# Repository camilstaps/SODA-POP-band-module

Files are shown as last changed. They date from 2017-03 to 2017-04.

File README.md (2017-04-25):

# SODA POP band module
This repository contains Eagle files for band modules for the
[SODA POP][sodapop] by [Steve Weber KD1JV][kd1jv]. The SODA POP was originally
designed as a single band QRP CW transceiver on a 3.6" square board. The mods
described below make it a multi-bander.

**Warning**: I have not actually tried to use these files yet. They may have
errors. I shall in no event be liable for any claim, damages or other
liability, whether in action of contract, tort or otherwise, arising from, out
of or in connection with these files or their use.

Two versions are available: one with headers and either through-hole or SMT
components; one with SMT components and a DB9 connector. The DB9 one has an
option for automatic band selection. Some modifications have to be made to the
main board for both modules.

The most recent version of these modules can be ordered from OSH Park from
https://oshpark.com/profiles/PD7LOL.

---

- [Common mods](#common-mods)
- [Through-hole / SMT module with headers](#through-hole--smt-module-with-headers)
- [SMT module with DB9 connector](#smt-module-with-db9-connector)
- [SMT module with DB9 connector and auto band selection](#smt-module-with-db9-connector-and-auto-band-selection)
- [Horizontal format SMT module with DB9 connector and auto band selection](#horizontal-format-smt-module-with-db9-connector-and-auto-band-selection)
- [Author &amp; license](#author--license)

---

## Common mods

### Main board
- The following components are moved to the band module:
	- **TX**: C2, C3, C5 (and C6), C12, L7, L8
	- **RX**: L3, CT1, C31, CT2, L4

	Their values can be taken from the manual under "Band specific parts". One
	part, C31, is on the band module even though it has a fixed value (5p).

### Software
- The software has to be adapted as described in the manual under "Manual band
  selection".

## Through-hole / SMT module With headers
- L3 has to be shorted (on the main board).
- Add 2-pin female headers on the place of L7 and L8
- Add 3-pin female headers on the place of CT1 and CT2 (middle pin should be
  removed)

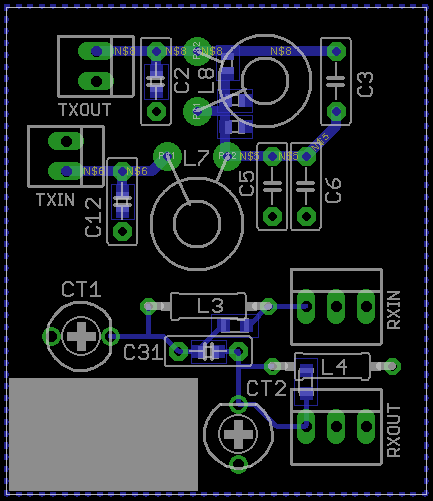
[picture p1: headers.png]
The PCB layout for <160m


If you want to make a 160m module with through-hole components, the layout is
slightly different to make room for the T50-2 toroids. Also, C31 is removed in
this case, and L4 is omitted (as in the manual). If building with SMT
components, you can use the same layout as for the other modules, short C31 and
leave out L4.

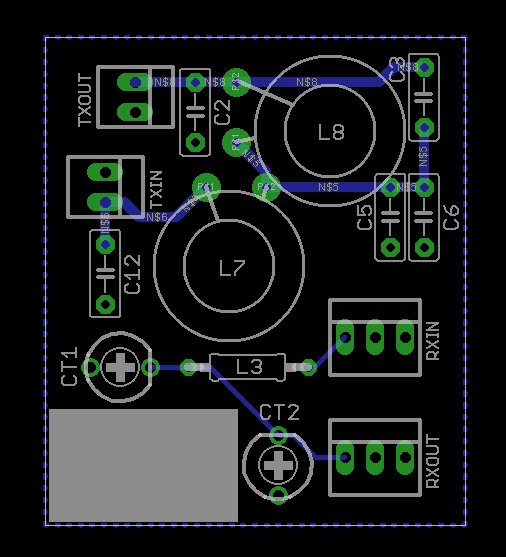
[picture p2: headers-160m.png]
The PCB layout for 160m


For 80m, there is no separate layout. Simply leave L4 empty and short C31.

For 60m and 80m, the T37-2 should fit on the normal board.

When plugged in, these band modules cover the ON/OFF switch on the main board.
I would suggest either mounting the switch on the case or omitting it (and turn
the rig on and off by applying and disconnecting a battery or power jack).

## SMT module with DB9 connector
- Add a (male) connector to the main board using short coax cables. The parts
  you should connect are L3, CT2, L7 and L8.

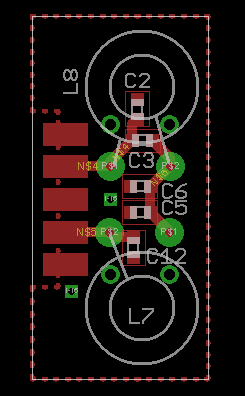
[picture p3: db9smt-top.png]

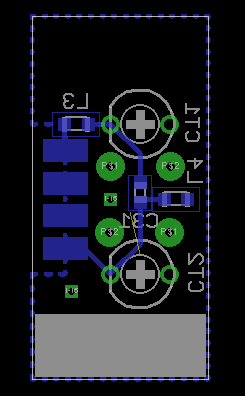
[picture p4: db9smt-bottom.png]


These files show T37-2 toroids, so they should work for all bands except 160m.
The T50-2 toroids for 160m will not fit any more, so they will extend beyond
the board boundaries.

The PCB is placed between the two rows of the DB9 connector.

## SMT module with DB9 connector and auto band selection
This is a very nice mod to the above module, contributed by
[David, VK3IL][vk3il]. It adds a [PCA9536][pca9536] that can be connected to
the I2C pins of the SODA POP controller to add automatic band selection. For
this, the firmware needs to be updated.

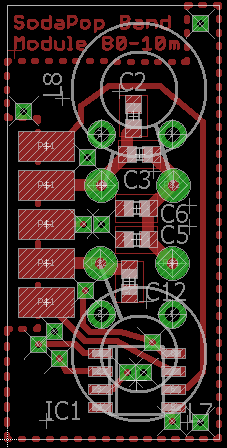
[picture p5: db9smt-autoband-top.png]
PCB layout for SMT/DB9/autoband, <160m

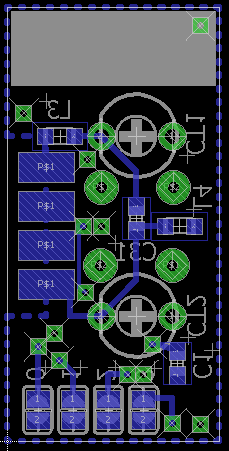
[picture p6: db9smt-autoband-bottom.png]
PCB layout for SMT/DB9/autoband, <160m


## Horizontal format SMT module with DB9 connector and auto band selection
This version is designed to mount parallel and above the main board using a
female DB9 connector on the module. It includes the auto-band selection feature
and is sized to support T30 to T50 size toroids so can be used for 160-10m
bands.

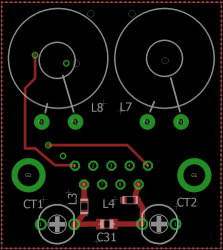
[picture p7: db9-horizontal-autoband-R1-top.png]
PCB layout for Horizontal SMT/DB9/autoband

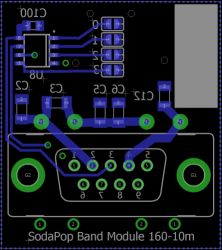
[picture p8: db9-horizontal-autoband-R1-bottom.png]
PCB layout for Horizontal SMT/DB9/autoband


## Author &amp; License
These files were made by [Camil Staps][cs], PD7LOL and [David Giddy][vk3il],
VK3IL. They are hereby placed in the public domain.

[cs]: https://camilstaps.nl
[kd1jv]: http://kd1jv.qrpradio.com/
[pca9536]: http://www.nxp.com/documents/data_sheet/PCA9536.pdf
[sodapop]: https://groups.yahoo.com/neo/groups/AT_Sprint/files/SODA%20POP/
[vk3il]: http://www.vk3il.net/

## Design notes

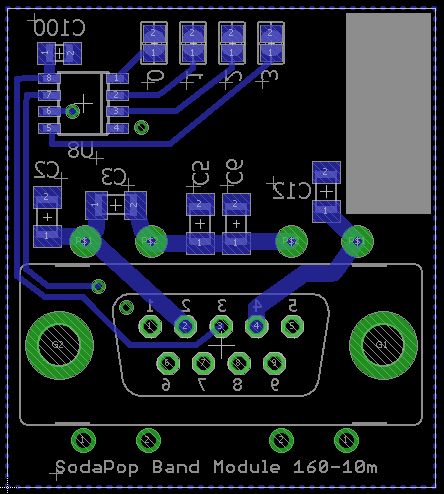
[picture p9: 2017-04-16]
db9-horizontal-autoband-bottom.png

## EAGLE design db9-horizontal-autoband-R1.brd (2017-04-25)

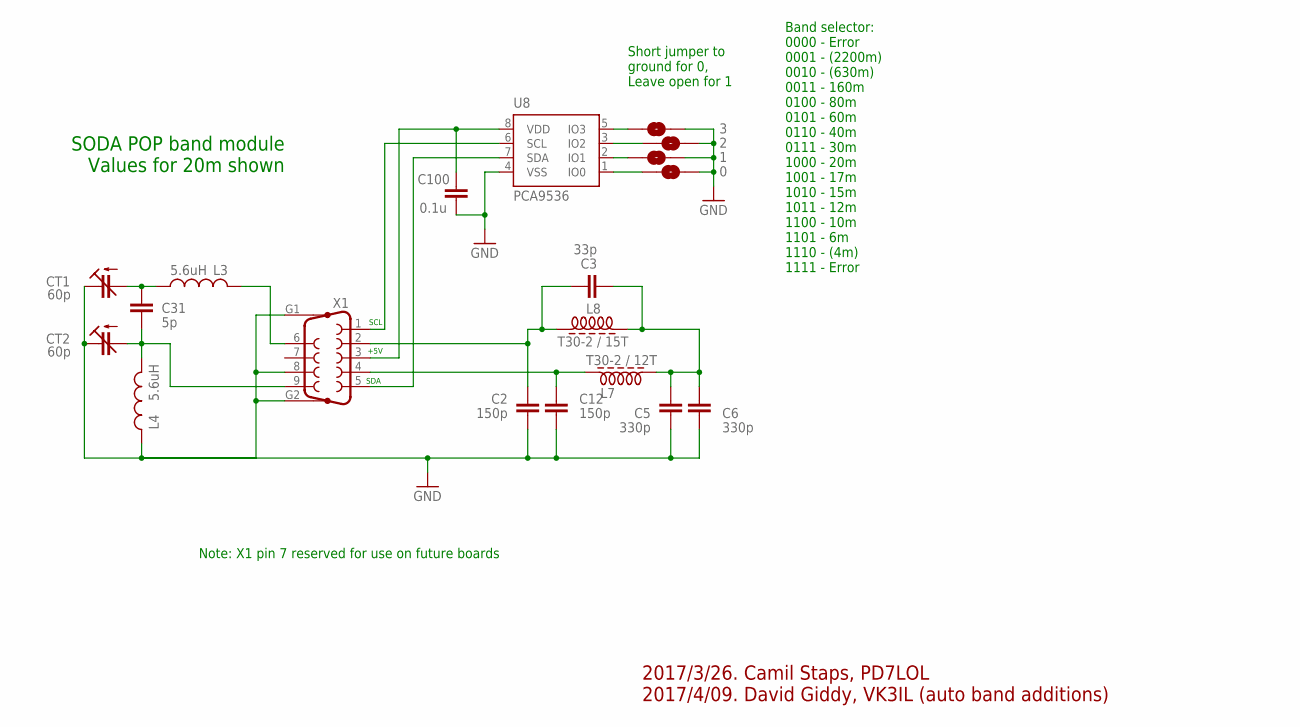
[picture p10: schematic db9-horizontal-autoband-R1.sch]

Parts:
0, 1, 2, 3: SJ
C2, C12: 150p; C1206K
C3: 33p; C1206K
C5, C6: 330p; C1206K
C31: 5p; C0805K
C100: 0.1u; C0805K
CT1, CT2: 60p; CTRIMTZ03
L3, L4: 5.6uH; L2012C
L7: T30-2 / 12T; T30-2-28AWG-15T
L8: T30-2 / 15T; T30-2-28AWG-15T
U8: PCA9536; SO8
X1: F09VP

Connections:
GND: 0.2, 1.2, 2.2, 3.2, C2.2, C5.2, C6.2, C12.2, C100.2, CT1.1 (E), CT2.1 (E), L4.2, U8.4 (VSS), X1.8, X1.G1, X1.G2
unnamed: C31.2, CT2.2 (A), L4.1, X1.9
unnamed: C31.1, CT1.2 (A), L3.2
unnamed: L3.1, X1.6
unnamed: C3.2, C5.1, C6.1, L7.P$2 (2), L8.P$2 (2)
unnamed: C12.1, L7.P$1 (1), X1.4
unnamed: C100.1, U8.8 (VDD), X1.3
unnamed: U8.6 (SCL), X1.1
unnamed: U8.7 (SDA), X1.5
unnamed: 3.1, U8.5 (IO3)
unnamed: 2.1, U8.3 (IO2)
unnamed: 1.1, U8.2 (IO1)
unnamed: 0.1, U8.1 (IO0)
unnamed: C2.1, C3.1, L8.P$1 (1), X1.2

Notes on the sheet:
SODA POP band module Values for 20m shown
2017/3/26. Camil Staps, PD7LOL 2017/4/09. David Giddy, VK3IL (auto band additions)
Band selector: 0000 - Error 0001 - (2200m) 0010 - (630m) 0011 - 160m 0100 - 80m 0101 - 60m 0110 - 40m 0111 - 30m 1000 - 20m 1001 - 17m 1010 - 15m 1011 - 12m 1100 - 10m 1101 - 6m 1110 - (4m) 1111 - Error
Short jumper to ground for 0, Leave open for 1
+5V
SCL
SDA
Note: X1 pin 7 reserved for use on future boards

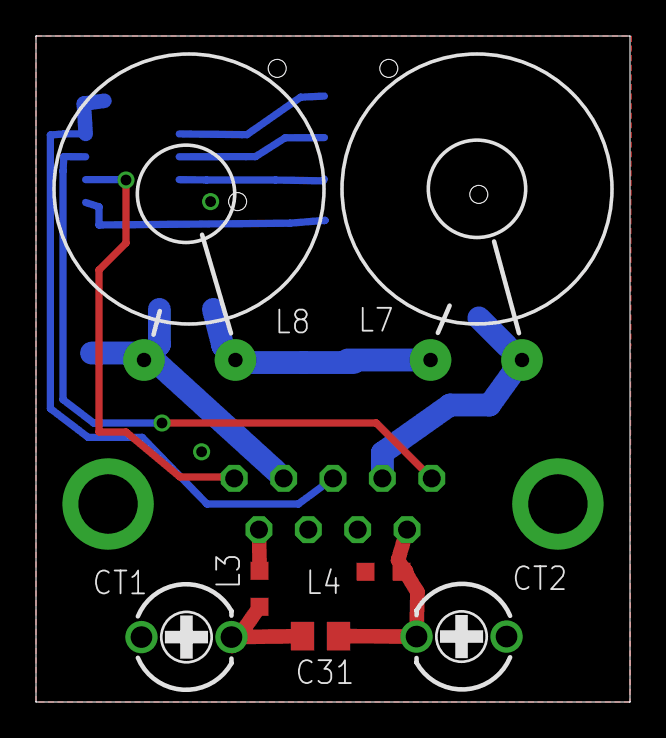
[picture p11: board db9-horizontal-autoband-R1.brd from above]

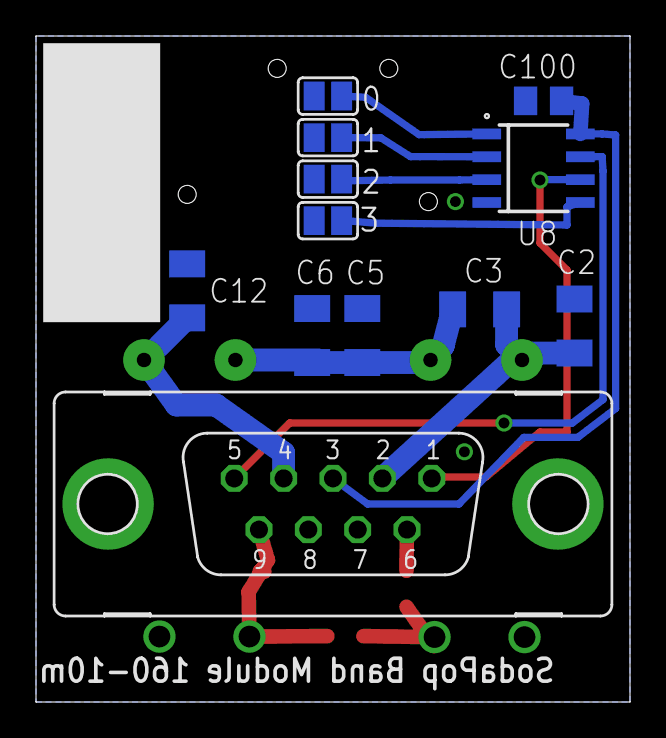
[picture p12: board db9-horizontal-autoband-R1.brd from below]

Board: 2 copper layers, 33.0 x 37.0 mm, 19 parts (12 on the bottom side), 14 nets.

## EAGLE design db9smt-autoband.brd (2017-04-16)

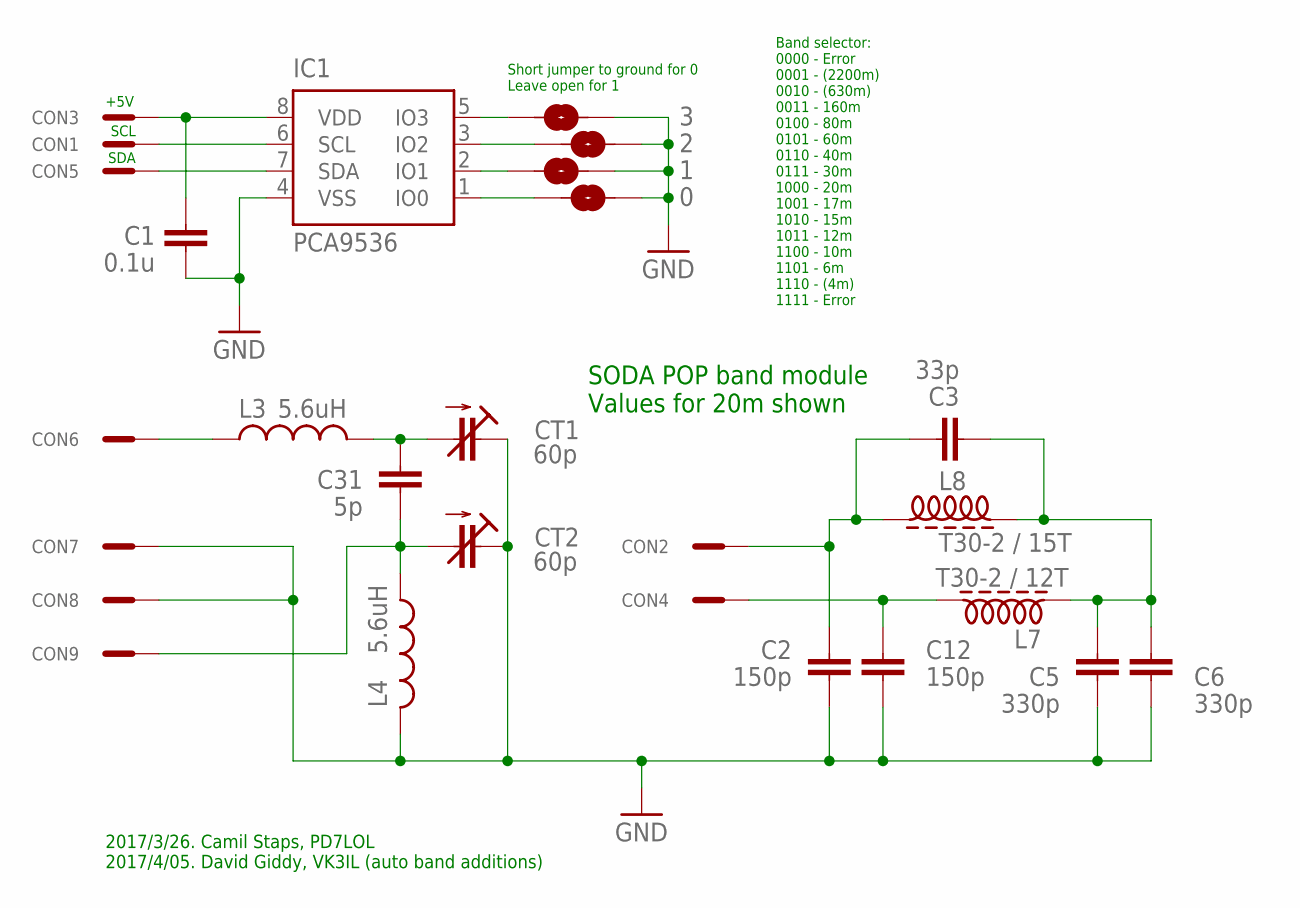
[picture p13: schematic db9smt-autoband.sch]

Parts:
0, 1, 2, 3: SJ
C1: 0.1u; C0603
C2, C12: 150p; C0603
C3: 33p; C0603
C5, C6: 330p; C0603
C31: 5p; C0603
CON1, CON2, CON3, CON4, CON5, CON6, CON7, CON8, CON9: PADONPRINT; PAD
CT1, CT2: 60p; CTRIMTZ03
IC1: PCA9536; SO8
L3, L4: 5.6uH; L2012C
L7: T30-2 / 12T; T30-2-28AWG-15T
L8: T30-2 / 15T; T30-2-28AWG-15T

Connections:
GND: 0.2, 1.2, 2.2, 3.2, C1.2, C2.2, C5.2, C6.2, C12.2, CON7.P$1, CON8.P$1, CT1.1 (E), CT2.1 (E), IC1.4 (VSS), L4.2
unnamed: C31.2, CON9.P$1, CT2.2 (A), L4.1
unnamed: C31.1, CT1.2 (A), L3.2
unnamed: CON6.P$1, L3.1
unnamed: C2.1, C3.1, CON2.P$1, L8.P$1 (1)
unnamed: C12.1, CON4.P$1, L7.P$2 (2)
unnamed: C3.2, C5.1, C6.1, L7.P$1 (1), L8.P$2 (2)
unnamed: C1.1, CON3.P$1, IC1.8 (VDD)
unnamed: CON1.P$1, IC1.6 (SCL)
unnamed: CON5.P$1, IC1.7 (SDA)
unnamed: 3.1, IC1.5 (IO3)
unnamed: 2.1, IC1.3 (IO2)
unnamed: 1.1, IC1.2 (IO1)
unnamed: 0.1, IC1.1 (IO0)

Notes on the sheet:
SODA POP band module Values for 20m shown
2017/3/26. Camil Staps, PD7LOL 2017/4/05. David Giddy, VK3IL (auto band additions)
Band selector: 0000 - Error 0001 - (2200m) 0010 - (630m) 0011 - 160m 0100 - 80m 0101 - 60m 0110 - 40m 0111 - 30m 1000 - 20m 1001 - 17m 1010 - 15m 1011 - 12m 1100 - 10m 1101 - 6m 1110 - (4m) 1111 - Error
Short jumper to ground for 0 Leave open for 1
+5V
SCL
SDA

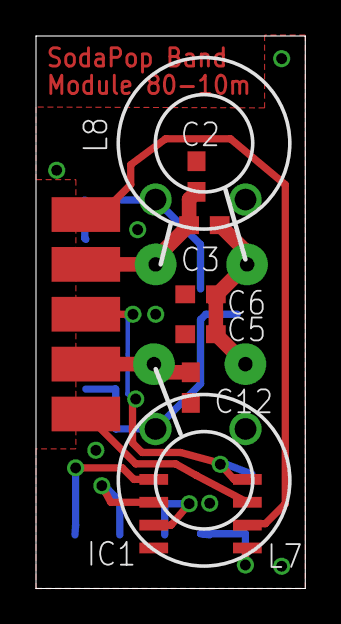
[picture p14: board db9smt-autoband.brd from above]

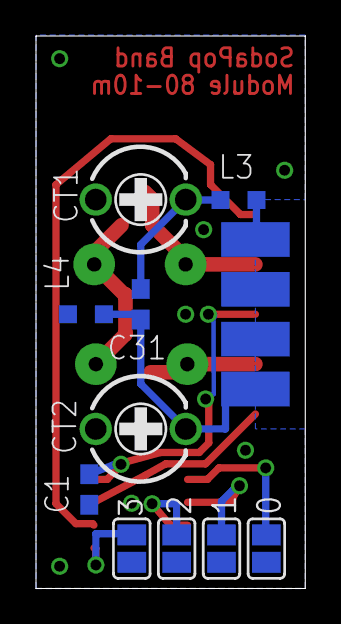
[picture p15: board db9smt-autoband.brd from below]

Board: 2 copper layers, 15.0 x 30.7 mm, 27 parts (14 on the bottom side), 14 nets.

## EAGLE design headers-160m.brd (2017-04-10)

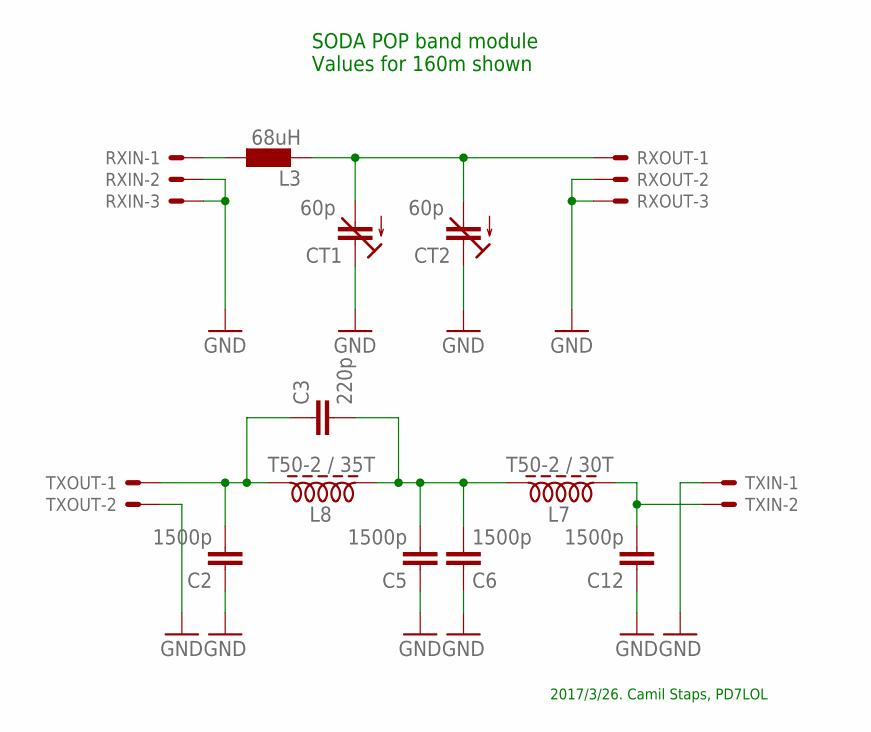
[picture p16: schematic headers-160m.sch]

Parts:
C2, C5, C6, C12: 1500p; C5B2.5
C3: 220p; C5B2.5
CT1, CT2: 60p; CTRIMTZ03
L3: 68uH; 0207/10
L7: T50-2 / 30T; T30-2-28AWG-15T
L8: T50-2 / 35T; T30-2-28AWG-15T
RXIN: 22-23-2031
RXOUT: 22-23-2031
TXIN: 22-23-2021
TXOUT: 22-23-2021

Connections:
GND: C2.1, C5.1, C6.1, C12.1, CT1.1 (E), CT2.1 (E), RXIN.2, RXIN.3, RXOUT.2, RXOUT.3, TXIN.1, TXOUT.2
unnamed: L3.1, RXIN.1
unnamed: CT1.2 (A), CT2.2 (A), L3.2, RXOUT.1
unnamed: C3.2, C5.2, C6.2, L7.P$2 (2), L8.P$1 (1)
unnamed: C12.2, L7.P$1 (1), TXIN.2
unnamed: C2.2, C3.1, L8.P$2 (2), TXOUT.1

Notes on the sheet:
SODA POP band module Values for 160m shown
2017/3/26. Camil Staps, PD7LOL

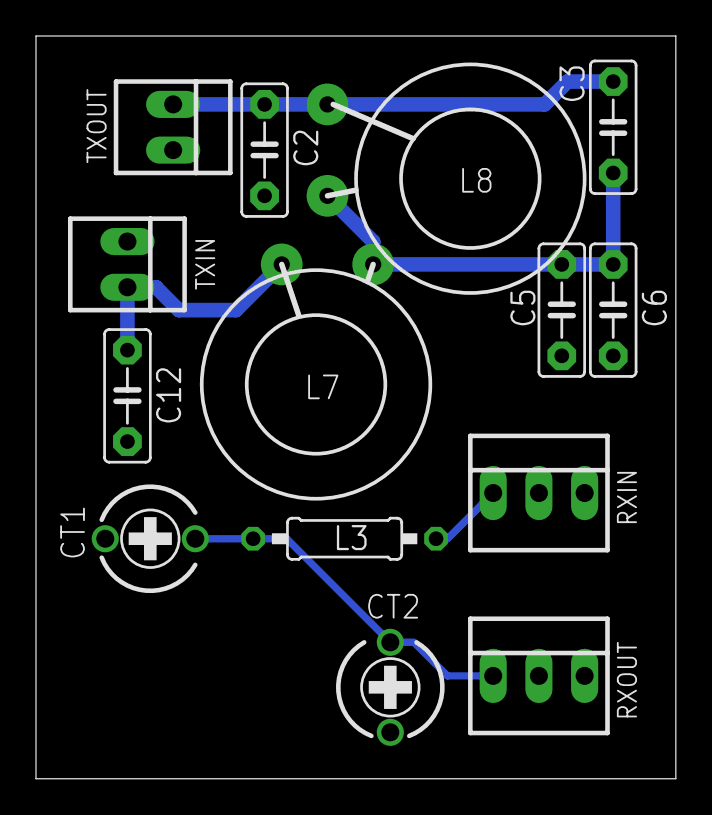
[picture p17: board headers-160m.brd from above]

Board: 2 copper layers, 35.5 x 41.3 mm, 14 parts (0 on the bottom side), 6 nets.

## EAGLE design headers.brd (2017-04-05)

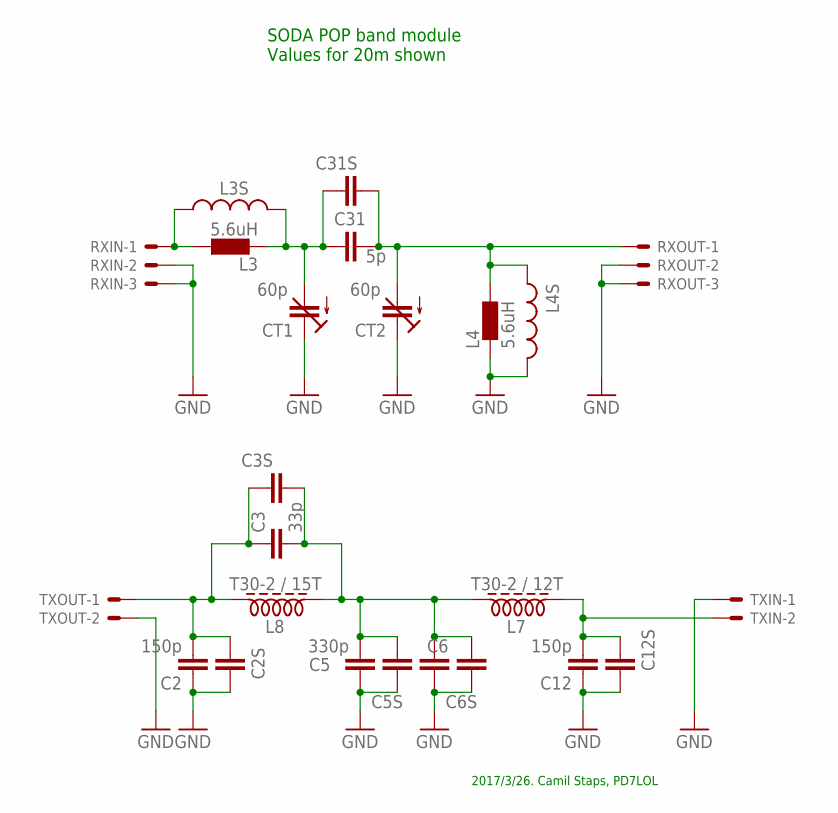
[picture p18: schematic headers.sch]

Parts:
C2, C12: 150p; C5B2.5
C2S, C3S, C5S, C6S, C12S, C31S: CC0603; C0603
C3: 33p; C5B2.5
C5, C6: 330p; C5B2.5
C31: 5p; C5B2.5
CT1, CT2: 60p; CTRIMTZ03
L3, L4: 5.6uH; 0207/10
L3S, L4S: L-USL2012C; L2012C
L7: T30-2 / 12T; T30-2-28AWG-15T
L8: T30-2 / 15T; T30-2-28AWG-15T
RXIN: 22-23-2031
RXOUT: 22-23-2031
TXIN: 22-23-2021
TXOUT: 22-23-2021

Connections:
GND: C2.1, C2S.2, C5.1, C5S.2, C6.1, C6S.2, C12.1, C12S.2, CT1.1 (E), CT2.1 (E), L4.2, L4S.2, RXIN.2, RXIN.3, RXOUT.2, RXOUT.3, TXIN.1, TXOUT.2
unnamed: L3.1, L3S.1, RXIN.1
unnamed: C31.1, C31S.1, CT1.2 (A), L3.2, L3S.2
unnamed: C31.2, C31S.2, CT2.2 (A), L4.1, L4S.1, RXOUT.1
unnamed: C3.2, C3S.2, C5.2, C5S.1, C6.2, C6S.1, L7.P$2 (2), L8.P$1 (1)
unnamed: C12.2, C12S.1, L7.P$1 (1), TXIN.2
unnamed: C2.2, C2S.1, C3.1, C3S.1, L8.P$2 (2), TXOUT.1

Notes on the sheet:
SODA POP band module Values for 20m shown
2017/3/26. Camil Staps, PD7LOL

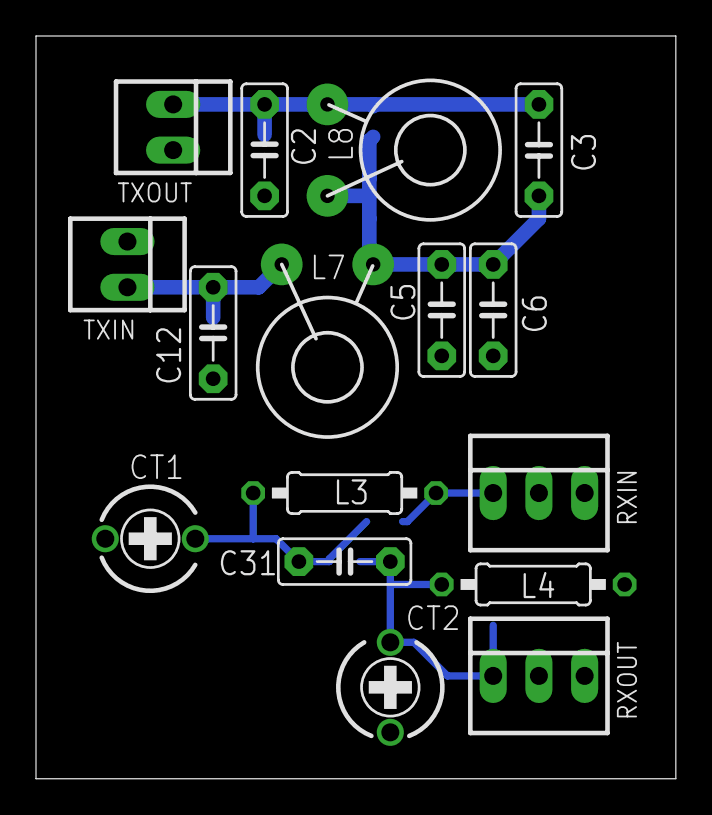
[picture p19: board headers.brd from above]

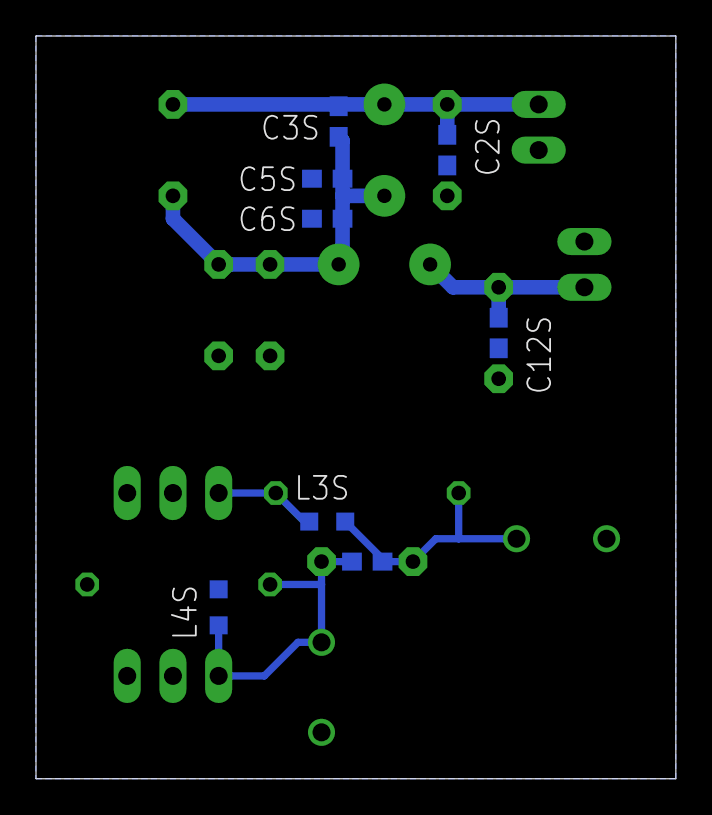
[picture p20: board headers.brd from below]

Board: 2 copper layers, 35.5 x 41.3 mm, 24 parts (8 on the bottom side), 7 nets.

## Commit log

2017-03-26 Initial version
    [bandmodule.brd, bandmodule.sch]
2017-03-26 Make board smaller
    [bandmodule.brd]
2017-03-26 Readme, made more space for toroids
    [bandmodule.brd, bandmodule.sch]
2017-03-26 Add gerber file
2017-03-26 Add warning and note about on off switch
2017-03-27 Move labels, add white rectangle for band
    [bandmodule.brd, bandmodule.sch]
2017-03-27 Split up C5-6
    [bandmodule.brd, bandmodule.sch]
2017-03-27 Move RX around for larger board note rectangle
    [bandmodule.brd, bandmodule.sch]
2017-03-27 Move labels
    [bandmodule.brd]
2017-03-28 Move L7 and L8 for more space; change artwork
    [bandmodule.brd, bandmodule.sch]
2017-03-28 Remove gerber
2017-03-28 Change toroid style
    [bandmodule.brd]
2017-03-28 Add separate 160m module
    [bandmodule-160m.brd, bandmodule-160m.sch]
2017-03-28 Fix polygon
    [bandmodule-160m.brd, bandmodule.brd]
2017-03-28 Made traces shorter
    [bandmodule.brd]
2017-03-28 SMT/DB9 version
    [db9smt.brd, db9smt.sch]
2017-03-28 Rename bandmodule -> headers
    [headers-160m.brd, headers-160m.sch, headers.brd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]
2017-03-28 Add note space on silk screen for db9smt
    [db9smt.brd]
2017-03-28 Increase trace width to make manufactering easier
    [db9smt.brd]
2017-03-28 Move bottom band note; OSHPark design rules
    [db9smt.brd]
2017-03-28 Smaller board
    [db9smt.brd]
2017-03-28 Nicer bottom silk screen
    [db9smt.brd]
2017-03-28 GND between signals, remove note space on backside
    [db9smt.brd, db9smt.sch]
2017-03-28 Removed right angle
    [db9smt.brd]
2017-03-30 Headers: split C5-6 again, make some TX traces shorter
    [headers-160m.brd, headers-160m.sch, headers.brd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]
2017-03-30 Make DB9 horizontal for smaller footprint and shorter traces
    [db9smt.brd, db9smt.sch]
2017-03-30 Move TX lines on DB9 connector
    [db9smt.brd, db9smt.sch]
2017-03-30 Minor fix DB9SMT
    [db9smt.brd]
2017-04-04 Automatic band selection on the DB9SMT modules (thanks VK3IL)
    [db9smt-autoband.brd, db9smt-autoband.sch]
2017-04-05 SMT components on the header module
    [headers.brd, headers.sch]
2017-04-05 Move SMT components to bottom
    [headers.brd]
2017-04-09 Added DB9 horizontal format files
    Added in a horizontal mount version of the DB9 module. Includes autoband
    capability. TX side capacitors upsized to 1206. Receive capacitor
    upsized to 0805.
    [db9-horizontal-autoband.brd, db9-horizontal-autoband.sch]
2017-04-10 Adjusted the hole size for the larger toroid pads to 0.9mm
    Adjusted the hole size to allow use of 0.8mm enamelled copper wire for
    the larger toroids. Larger wire provides better rigidity and marginally
    lower loss.
    [db9-horizontal-autoband.brd, db9-horizontal-autoband.sch, headers-160m.brd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]
2017-04-13 Fixed hole size on trimmer cap
    Fixed hole size on trimmer cap in library PCA9536.lbr and updated the
    two autoband boards to use the corrected package. Package can be
    replaced on other boards with the one in this library to fix the
    problem. Also moved the text on the horizontal board to the bPlace
    layer. Couldn't do this on the smaller board as no where to put it!
    [db9-horizontal-autoband.brd, db9-horizontal-autoband.sch, db9smt-autoband.brd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]
2017-04-25 Fixed errors on horizontal autoband module
    Errors fixed:
    - Disconnected DB9 pin 7 to allow for future use
    - Added 1mm holes to allow toroids to be tied down
    - Moved solder jumpers to make room forholes
    - Fixed board title text so that it will actually print
    - Adjusted restrict on board edge to be narrower
    - Minor text placement fixes
    [db9-horizontal-autoband-R1.brd, db9-horizontal-autoband-R1.sch]
